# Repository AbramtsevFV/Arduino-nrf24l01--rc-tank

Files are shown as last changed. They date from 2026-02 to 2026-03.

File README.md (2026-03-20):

# Arduino nrf24l01  rc tank
## Проект созданный для развлечения. Состоит из: 
- Двух радиом одулей nRF24L01 с усилителем, а также модули питания. [Подключение ссылка на видео Alex Gyver ](https://www.youtube.com/watch?v=ACVtKDJVXS4)
- Двух Arduino Nano
- Одиного модуль L298N управление двигателями [Подключение](https://alexgyver.ru/wp-content/uploads/2021/07/l298.jpg) . 
- Шеcти АКБ 18650
- Трёх батарейных отсеков для аккумуляторов Li-ion типоразмера 18650 [Можно такие](https://www.ozon.ru/product/batareynyy-otsek-2h-dlya-akkumulyatorov-li-ion-tiporazmera-18650-s-kryshkoy-arduino-slot-930989918/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)
- Гусеничное шасси [Использовал такое](https://www.ozon.ru/product/umnaya-gusenichnaya-platforma-robot-na-shassi-tsisterny-s-dvumya-dvigatelyami-postoyannogo-toka-12-v-2890905784/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)
- Джойстика (стика) [Использовал такой](https://www.ozon.ru/product/dvuhkoordinatnyy-modul-dzhoystika-xy-datchik-rychaga-upravleniya-dzhoystikom-ps2-ky-023-dlya-arduino-2153603120/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)
- Потенциометр с ручкой.
- Два выключателя [Использовал такие](https://www.ozon.ru/product/knopka-vyklyuchatel-tumbler-on-off-10-15-mm-kcd11-1770572766/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)
- Проводов. Изначально использовал витую пару — не лучший выбор. Потом просто откусил пины от проводов для макетных плат и использовал их для соединения сигнальных контактов. [Например такие](https://aliexpress.ru/item/32996173648.html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)
- DC-DC преобразователя на 5 вольт.
- Для скручивания — латунные шайбы М3.
- Сервопривода для вращения башни.
- Лазерный модуль для башни TZT KY-008. 
### Добавлено
В проект добавлено мигание светодиодом, который показывает состояние танка, мигание дыхание указывает на отсутствие сигнала, частое мигание указывает на состояние готовности и сигнал получет от пульта. На данный момент это реализовано на milles, так как не хватило пинов ШИМ, но заказан модуль PCA9685PW, тогда переделаю на шим, сами функции мигания на ШИМ в проекте тоже есть. 

 ## Сборка
Важно: контакт 5V на модуле L298N не подключать, так как 4 аккумулятора 18650 в сумме дают около 16 вольт, а этот пин рассчитан только на 12В. Логику модуля (контакт +5V) питаем, как и всё остальное, от DC-DC преобразователя.
Также перед загрузкой прошивки рекомендую проверить радиочасты и выбрать наименее зашумленные. Для проверки я использовал прошивку Алекса Гайвера. [Ссылка](https://github.com/AlexGyver/nRF24L01/blob/master/nRF24L01%20tests/nrf_listen_air/nrf_listen_air.ino)
Прошивки лежат в папке Firmware. 
- Пульт [tank_remote_control_transmitter](https://github.com/AbramtsevFV/Arduino-nrf24l01--rc-tank/tree/main/Firmware/tank_remote_control_transmitter).
- Танк [tank_motor_receiver](https://github.com/AbramtsevFV/Arduino-nrf24l01--rc-tank/tree/main/Firmware/tank_motor_receiver)

 Все 3d модели печатались пластиком PLA.

 ## Фото готового проекта 
 <div align="center">
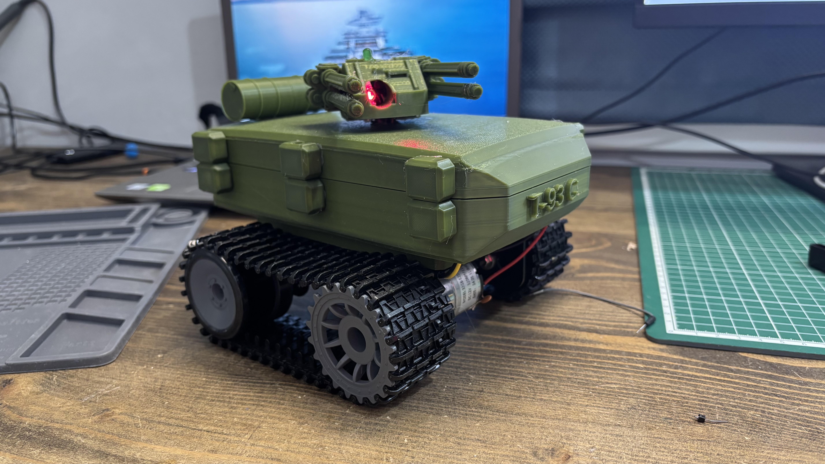
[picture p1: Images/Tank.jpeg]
   
    <p> Рисунок 1 - Готовый танк </p>
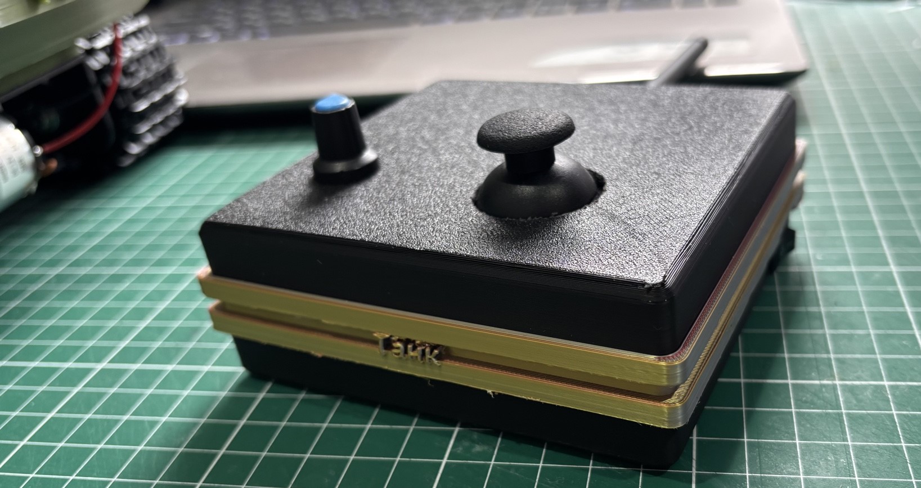
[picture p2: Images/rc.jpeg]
   
    <p> Рисунок 2 - ульт управления в сборе </p>
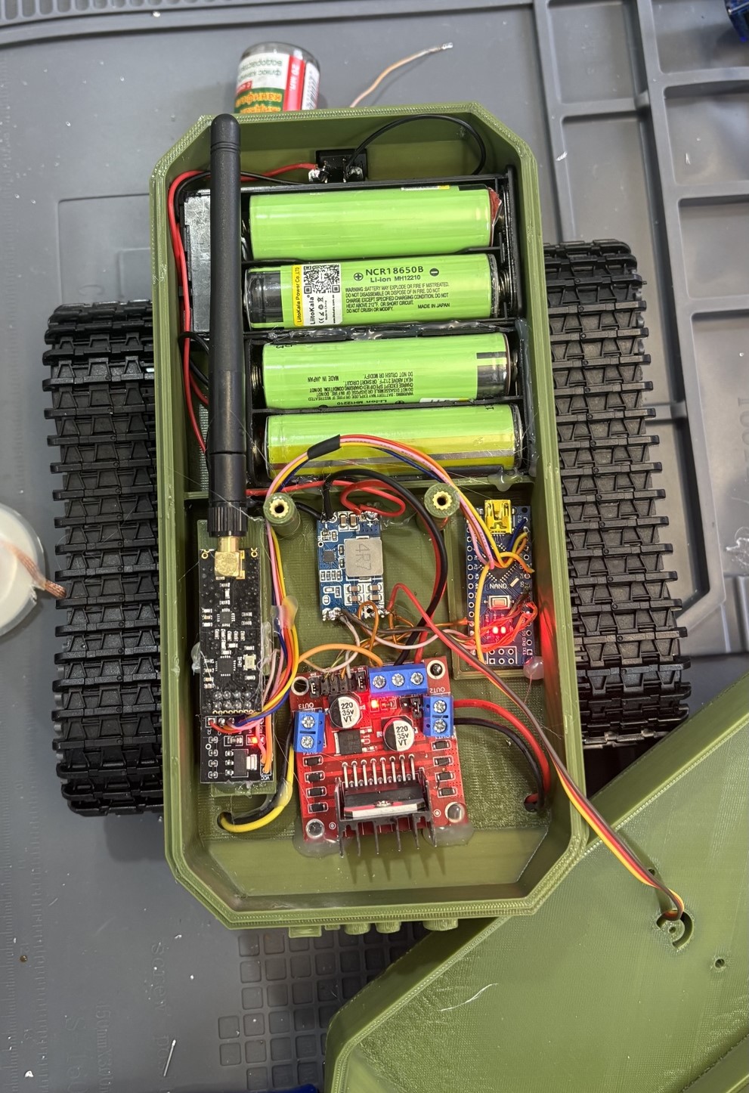
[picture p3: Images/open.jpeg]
   
    <p> Рисунок 3 - Компановка деталей в танке </p>
 </div>

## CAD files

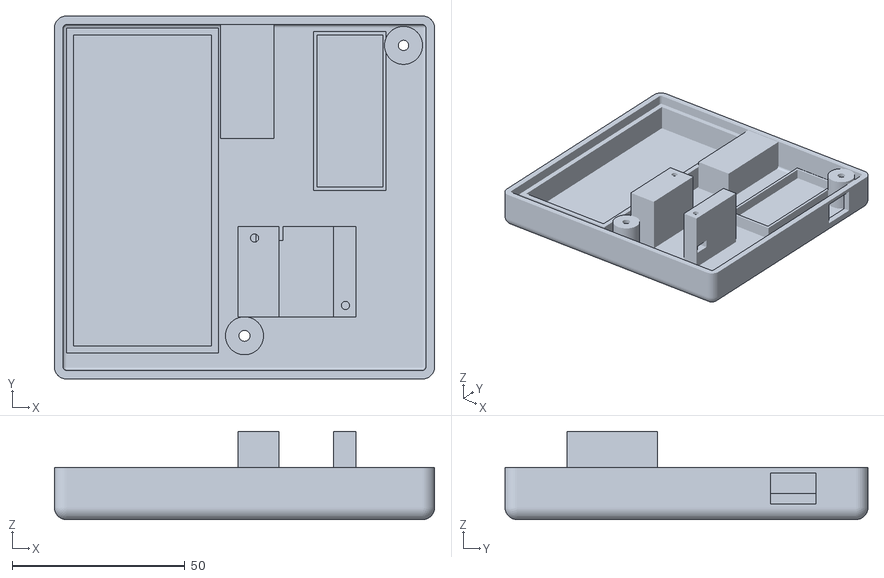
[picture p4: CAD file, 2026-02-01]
3d model/RC/RC_TANK_Bottom.stl
110.0 x 105.0 x 25.5

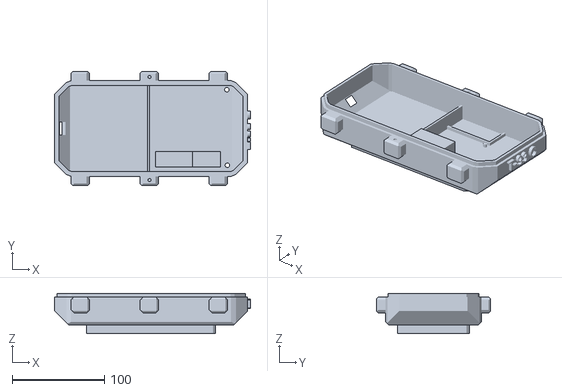
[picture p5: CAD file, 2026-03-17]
3d model/tank turret/tank turret buttom electronics compartment.stl
213.0 x 124.0 x 43.5

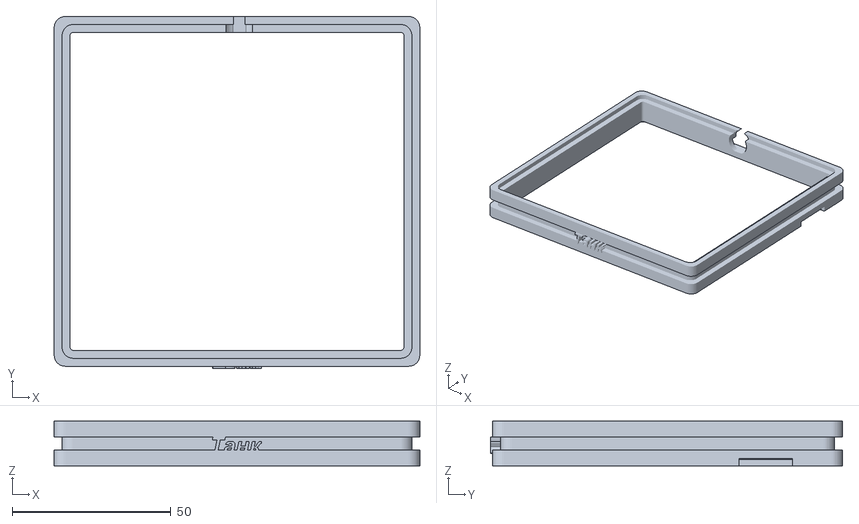
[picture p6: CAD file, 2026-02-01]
3d model/RC/RC_TANK_middle_part.stl
115.0 x 110.7 x 14.0

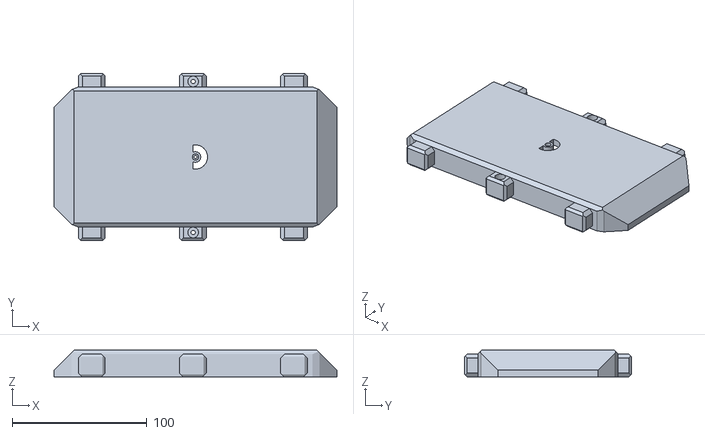
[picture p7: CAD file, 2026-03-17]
3d model/tank turret/tank turret top electronics compartment.stl
210.0 x 124.0 x 20.0

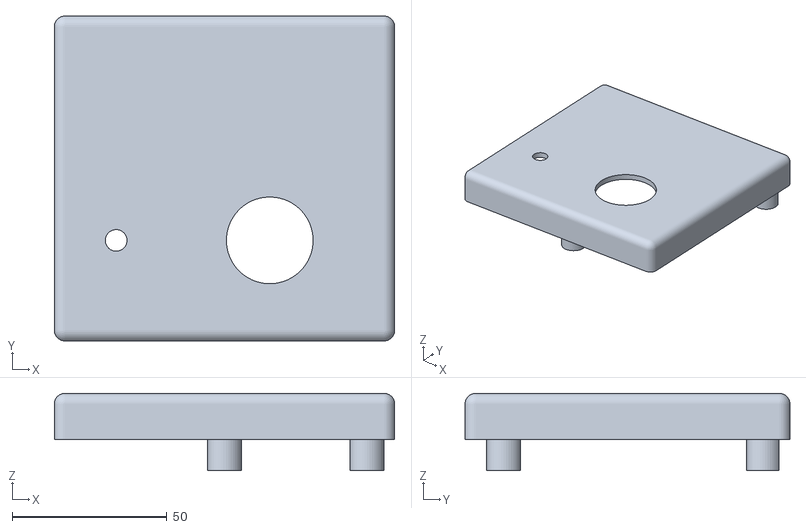
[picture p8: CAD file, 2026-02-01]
3d model/RC/RC_TANK_TOP.stl
110.0 x 105.0 x 25.0

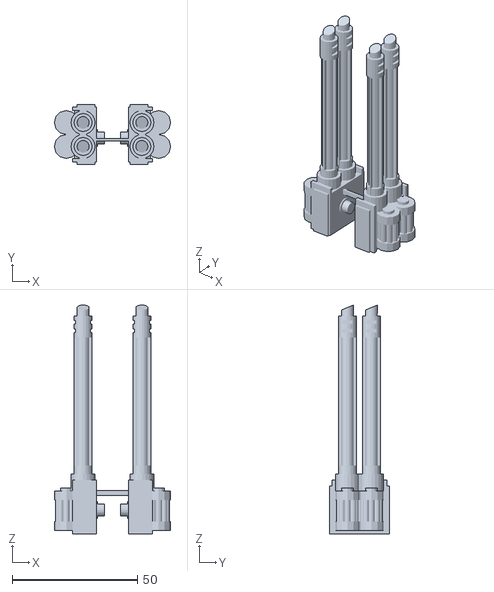
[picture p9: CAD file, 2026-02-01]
3d model/tank turret/Guns_Tank.stl
46.5 x 23.9 x 91.5

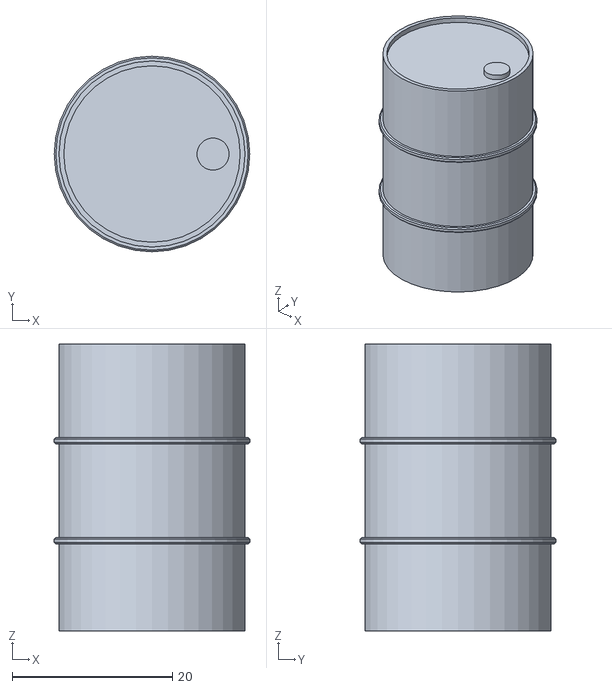
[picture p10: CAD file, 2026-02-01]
3d model/tank turret/200-L.STL
24.4 x 24.4 x 35.8

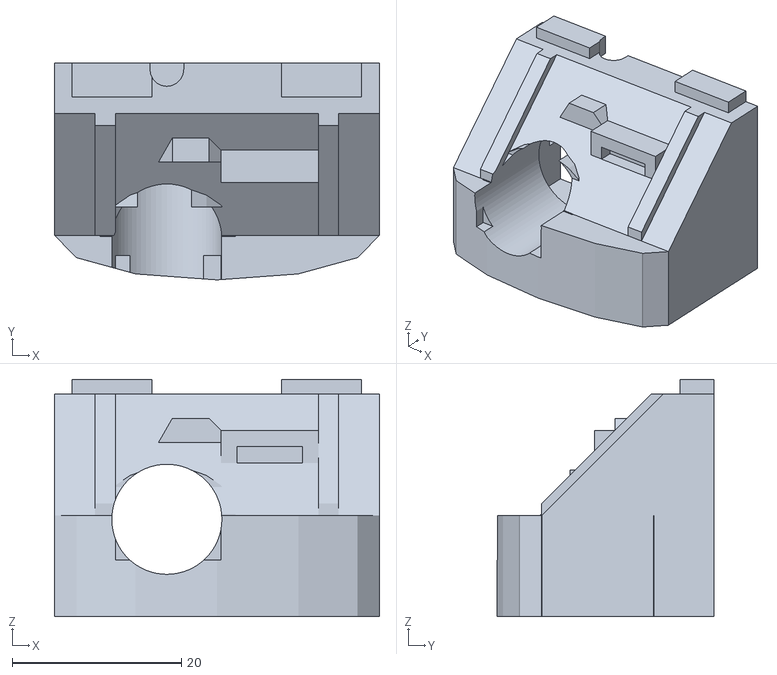
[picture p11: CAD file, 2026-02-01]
3d model/tank turret/Turret_Front_Tank.stl
38.4 x 25.6 x 28.0

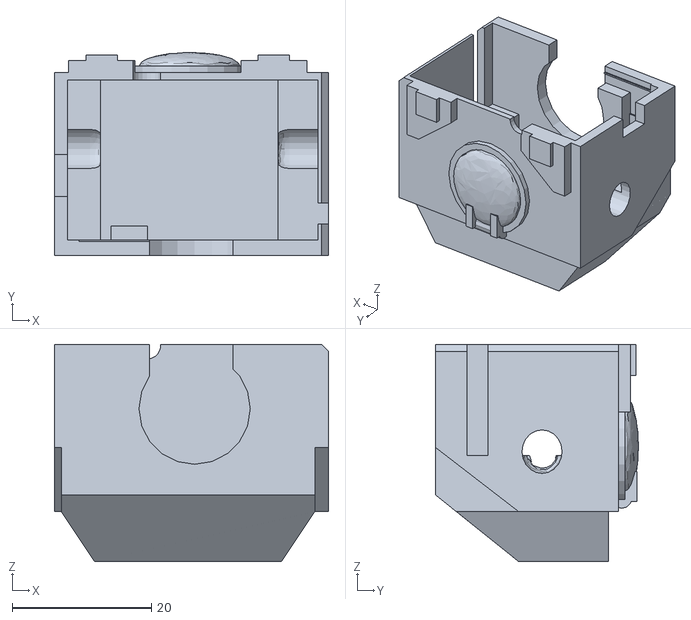
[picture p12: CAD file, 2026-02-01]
3d model/tank turret/Turret_Rear_Tank.stl
39.4 x 29.2 x 31.3

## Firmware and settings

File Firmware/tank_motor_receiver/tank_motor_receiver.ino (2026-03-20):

#include <GyverMotor.h>
#include <SPI.h>
#include "nRF24L01.h"
#include "RF24.h"
#include <Servo.h>



// уапавление моторами
byte motor_r_dig_pin = 4; //2
byte motor_r_PWM_pin = 5; //3

byte motor_l_dig_pin = 2; //4
byte motor_l_PWM_pin = 3; //5

GMotor motor_R(DRIVER2WIRE, motor_r_dig_pin, motor_r_PWM_pin);
GMotor motor_L(DRIVER2WIRE, motor_l_dig_pin, motor_l_PWM_pin);


// Создаём приёмник
RF24 radio(9, 10);  // "создать" модуль на пинах 9 и 10 Для Уно
byte address[][6] = {"1Node", "2Node", "3Node", "4Node", "5Node", "6Node"}; //возможные номера труб

// создаём servo 
Servo servo;
byte SERV_PIN = 6;

// Создаём лед
unsigned long lastUpdate = 0;
#define GREEN_PIN 7
unsigned long lastSignalTime = 0;
const unsigned long SIGNAL_TIMEOUT = 200; // 200ms

// временно 
// будет заменено на шим когда прийдёт PCA9685PW 
void airBlink();
unsigned long previousMicros = 0;
const long pwmInterval = 100; // Период ШИМ в микросекундах
int dutyCycle = 0; // Заполнение 0-100
int breathDirection = 1;
unsigned long breathTimer = 0;
const long breathInterval = 20; // Обновление дыхания каждые 20ms

short recieved_data[4];  // массив принятых данных


void setup() {
  Serial.begin(9600);
  // Настройки приёмника
  radio.begin(); //активировать модуль
  radio.setAutoAck(1);        // режим подтверждения приёма, 1 вкл 0 выкл
  radio.setRetries(0, 15);    // (время между попыткой достучаться, число попыток)
  radio.enableAckPayload();   // разрешить отсылку данных в ответ на входящий сигнал
  radio.setPayloadSize(32);   // размер пакета, в байтах

  radio.openReadingPipe(1, address[0]);     // хотим слушать трубу 0 
  radio.setChannel(0x6e);  // выбираем канал (в котором нет шумов!)

  radio.setPALevel (RF24_PA_MAX);   // уровень мощности передатчика. На выбор RF24_PA_MIN, RF24_PA_LOW, RF24_PA_HIGH, RF24_PA_MAX
  radio.setDataRate (RF24_1MBPS); // скорость обмена. На выбор RF24_2MBPS, RF24_1MBPS, RF24_250KBPS
  //должна быть одинакова на приёмнике и передатчике!
  //при самой низкой скорости имеем самую высокую чувствительность и дальность!!

  radio.powerUp();          // начать работу
  radio.startListening();   // начинаем слушать эфир, мы приёмный модуль

  // настройки моторов
  // установка скорости изменения скорости (ускорения) мотора
  motor_R.setSmoothSpeed(20);
  motor_L.setSmoothSpeed(20);
  motor_R.setMode(AUTO);
  motor_L.setMode(AUTO);

  // настройка servo
  servo.attach(SERV_PIN);
  pinMode(GREEN_PIN, OUTPUT);

  pinMode(A1, OUTPUT);


}

void loop() {
  byte pipeNo;
  while ( radio.available(&pipeNo)) { // есть входящие данные
     lastSignalTime = millis();
    // чиатем входящий сигнал
    radio.read(&recieved_data, sizeof(recieved_data));

    // управляем моторами
    motor_R.setSpeed(recieved_data[0]);
    motor_L.setSpeed(recieved_data[1]);
   
    //управляем servo
 
    int new_pos = recieved_data[2];
    servo.write(new_pos);
    
    //управление лазером
    digitalWrite(A1, recieved_data[3]);
    
    //управление индикацией наличия радиосигнала
    digitalWrite(GREEN_PIN, millis() % 500 > 250);
    
  }

   if (millis() - lastSignalTime > SIGNAL_TIMEOUT){
      // Время отключения сигдлнала для избежания ложных срабатываний
      airBlink();   
      // защита для моторов 
      motor_R.setSpeed(0);
      motor_L.setSpeed(0);
   }

}



   
 void airBlink(){
    unsigned long currentMicros = micros();
    unsigned long currentMillis = millis();
    
    // Генерация программного ШИМ
    if (currentMicros - previousMicros >= pwmInterval) {
      previousMicros = currentMicros;
      
      static int pwmCounter = 0;
      pwmCounter++;
      if (pwmCounter >= 100) pwmCounter = 0;
      
      if (pwmCounter < dutyCycle) {
        digitalWrite(GREEN_PIN, HIGH);
      } else {
        digitalWrite(GREEN_PIN, LOW);
      }
    }
    
    // Обновление эффекта дыхания
    if (currentMillis - breathTimer >= breathInterval) {
      breathTimer = currentMillis;
      
      dutyCycle += breathDirection;
      
      if (dutyCycle <= 0 || dutyCycle >= 100) {
        breathDirection = -breathDirection;
      }
    }
 }

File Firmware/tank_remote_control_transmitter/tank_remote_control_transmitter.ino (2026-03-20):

#include <SPI.h>
#include "nRF24L01.h"
#include "RF24.h"

#define BTN_DEB 50      // тай-маут смены состояния, мс
//bool stop = false;
const int POT = A2;   // Потенциометр для упраления башней
const int BUTTON_PIN = 4;
RF24 radio(9, 10); // "создать" модуль на пинах 9 и 10 Для Уно и нано

byte address[][6] = {"1Node", "2Node", "3Node", "4Node", "5Node", "6Node"}; //возможные номера труб

// Пины с джойстика по осям
const int X_PIN = A0;
const int Y_PIN = A1;

// Для отключения передатчика если данные не изменились и экономии энепгии
short transmit_data[4];  // массив, хранящий передаваемые данные

void button_press();



void setup() {

  Serial.begin(9600);

  radio.begin();              // активировать модуль
  radio.setAutoAck(1);        // режим подтверждения приёма, 1 вкл 0 выкл
  radio.setRetries(0, 15);    // (время между попыткой достучаться, число попыток)
  radio.enableAckPayload();   // разрешить отсылку данных в ответ на входящий сигнал
  radio.setPayloadSize(32);   // размер пакета, в байтах

  radio.openWritingPipe(address[0]);  // мы - труба 0, открываем канал для передачи данных
  radio.setChannel(0x6e);     // выбираем канал (в котором нет шумов!)

  radio.setPALevel (RF24_PA_MAX);   // уровень мощности передатчика. На выбор RF24_PA_MIN, RF24_PA_LOW, RF24_PA_HIGH, RF24_PA_MAX
  radio.setDataRate (RF24_1MBPS); // скорость обмена. На выбор RF24_2MBPS, RF24_1MBPS, RF24_250KBPS
  //должна быть одинакова на приёмнике и передатчике!
  //при самой низкой скорости имеем самую высокую чувствительность и дальность!!

  radio.powerUp();        //начать работу
  radio.stopListening();  //не слушаем радиоэфир, мы передатчик
  pinMode(BUTTON_PIN, INPUT_PULLUP);
}

void loop() {

  //  Переводим Аналоговый 0 -1023 в - 255  +255 ШИМ

  int X = (255 - (analogRead(X_PIN) + 9) / 2) *-1;
  int Y = (255 - (analogRead(Y_PIN) +9) / 2);

  // Преазуем значения в значения для управления
  int m_r = X + Y;
  int m_l = Y - X;
  button_press();
  transmit_data[0] = m_r;
  transmit_data[1] = m_l;
  transmit_data[2] = map(analogRead(POT), 0, 1023, 0, 180);
  radio.write(&transmit_data, sizeof(transmit_data)); // отправить по радио
  Serial.println(transmit_data[3]);
}

void button_press(){
  static bool pState = false;
    static uint32_t tmr;
    bool state = !digitalRead(BUTTON_PIN);

    if (pState != state) {
        if (!tmr) tmr = millis();               // первое изменение
        else if (millis() - tmr >= BTN_DEB) {   // вышел тайм-аут
            pState = state;                     // запомнить состояние

            if (state) transmit_data[3] = true;  // кнопка нажата
            else transmit_data[3] = false;        // кнопка отпущена
        }
    } else tmr = 0;  // сброс
}

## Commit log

2026-02-04 Update tank_motor_receiver.ino
    Добавлена индикация состояния светодиодом
2026-02-06 Update tank_motor_receiver.ino
    Реализовано мигание на milles
2026-03-17 крепления
    Передела крепления
    [tank turret buttom electronics compartment.stl, tank turret top electronics compartment.stl]
2026-03-20 обновление
    Добавил лазер
2026-03-20 новое фото
